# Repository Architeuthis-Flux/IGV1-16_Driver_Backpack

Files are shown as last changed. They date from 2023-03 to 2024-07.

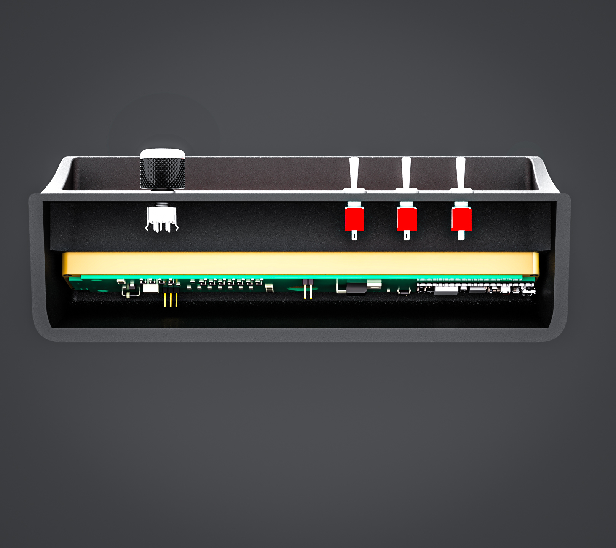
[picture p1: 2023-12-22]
Hardware/Enclosure_New Style/Renders/compass3_inclinometerStyled_2023-Jun-18_10-15-27PM-000_CustomizedView31835428946_png.jpg

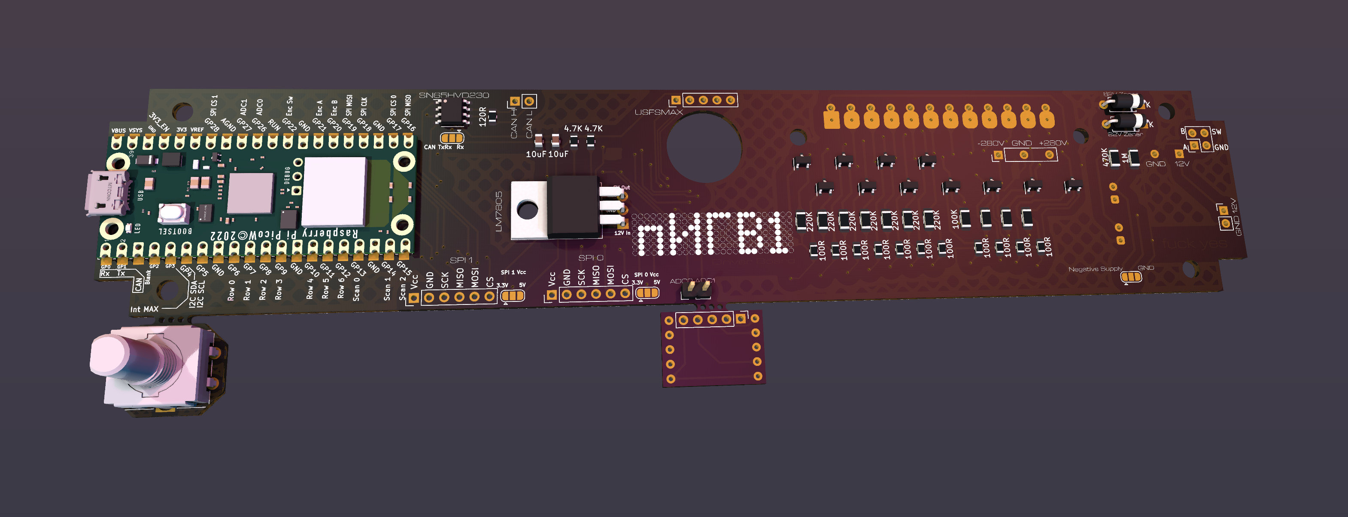
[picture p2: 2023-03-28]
Hardware/Screenshot 2023-03-19 at 2.08.38 PM.png

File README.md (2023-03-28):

# IGV1-16 Driver Backpack
This is a board that screws onto the back of an IGV1-16, GIPS-16 or Burroughs Self-Scan and handles the HV buffering between it and a RPi Pico W, among other things. 

[Here's the Hackaday.io page with more details about some of the hardware involved](https://hackaday.io/project/190028-igv1-16-car-compass)





I made a thing to handle the mess of wiring from the [IGV1-16 Compass](https://github.com/Architeuthis-Flux/IGV1-16-Compass) but I had a ton of extra board space and GPIO so I ended up making a somewhat generalized development board for these plasma scan displays. 

IGV1

Soon I'll be adding some code here that will be easier to use with whatever you end up doing with your plasma scan display. That other repo is just a small amount of display handling shoved into a huge mess of [USFSMAX sensor fusion module](https://github.com/gregtomasch/USFSMAX_MMC_Module/tree/master/MMC_USFS_MAX_Module_Dragonfly_Simple_Host_Utility_v0.0) code, and I'd like for people to be able to make this display show anything they like and not be confined to one specific use. 



For now, this is just the Kicad files for the hardware and some basic driving code for the Pico will be added in the next couple days. If you hve an idea for something cool to do with one of [these displays](https://www.ebay.com/itm/224643685691), let me know and I'll make sure you get a backpack board to play with. 

It uses one of these [cheap bipolar HV power supply modules](https://www.ebay.com/itm/295529826686) to generate the +280V and the (optional) -82V to drive the display. If you end up with one of these modules without the negative supply, there's a solder jumper on the board to instead drive the Blank line to ground. In which case it just needs to be held low a bit longer, giving you a bit less time to do other things between screen updates, but otherwise is totally fine.  





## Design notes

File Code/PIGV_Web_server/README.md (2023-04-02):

# pIGV-16 Web server scrolling text
This is code to have the Pico W host a simple web server that allows you to write text to be scrolled on the display

I'm using the [Arduino-Pico](https://github.com/earlephilhower/arduino-pico) core for this

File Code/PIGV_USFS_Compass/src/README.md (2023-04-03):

# pIGV1 Compass

This is the code for the car compass. 

It uses the [Arduino Pico](https://github.com/earlephilhower/arduino-pico) core and interfaces with a [USFSMAX Module](https://www.tindie.com/products/onehorse/usfsmax-module-and-carrier/) using [this excellent libraryification of the original interface code](https://github.com/PhiJu5/USFSMAX). But you don't need to download it, it's included in the files here because I needed to make a few modifications.

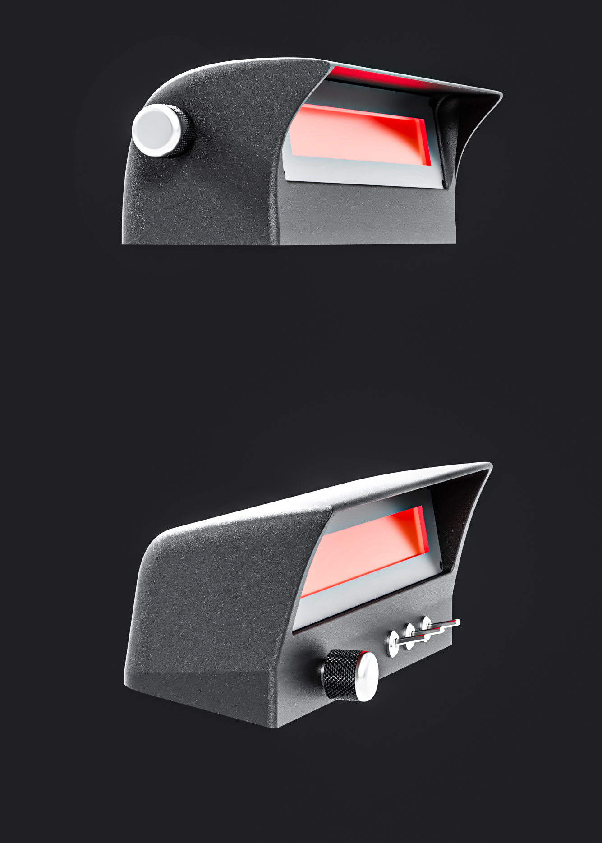
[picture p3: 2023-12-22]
Hardware/Enclosure_New Style/Renders/compass3_inclinometerStyled_2023-Jun-18_09-27-02PM-000_CustomizedView1432547207_png.jpg

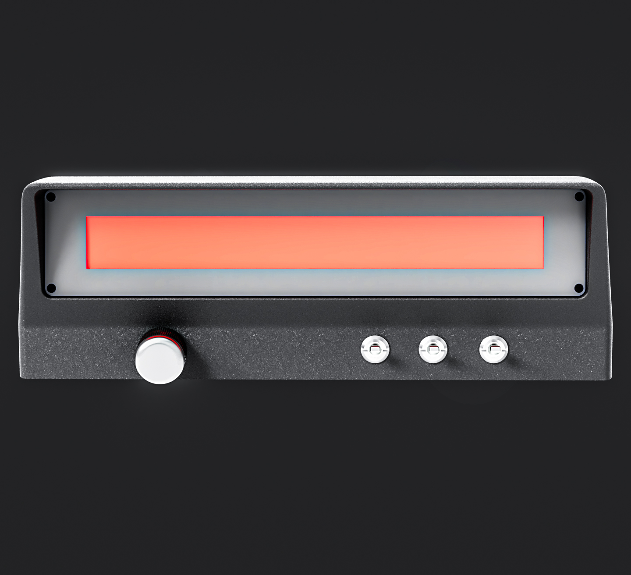
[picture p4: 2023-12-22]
Hardware/Enclosure_New Style/Renders/compass3_inclinometerStyled_2023-Jun-18_10-14-51PM-000_CustomizedView15648716872_png.jpg

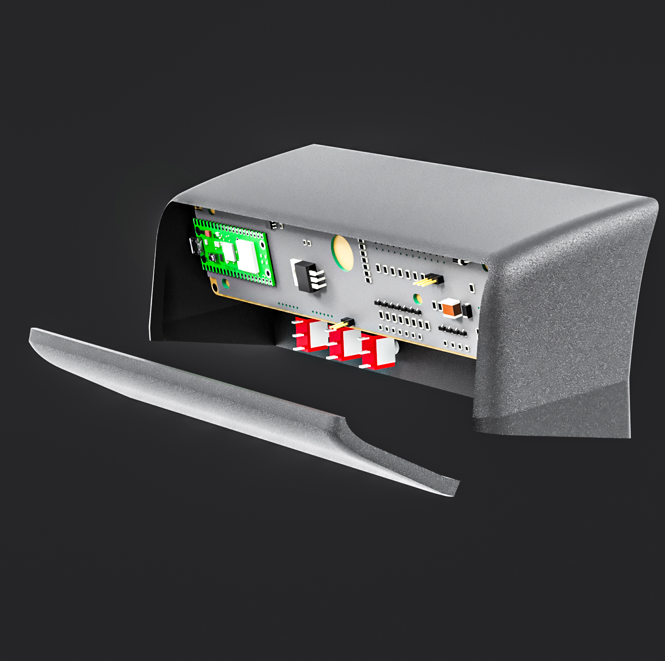
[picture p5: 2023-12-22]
Hardware/Enclosure_New Style/Renders/compass3_inclinometerStyled_2023-Jun-18_10-05-42PM-000_CustomizedView15776161031_png.jpg

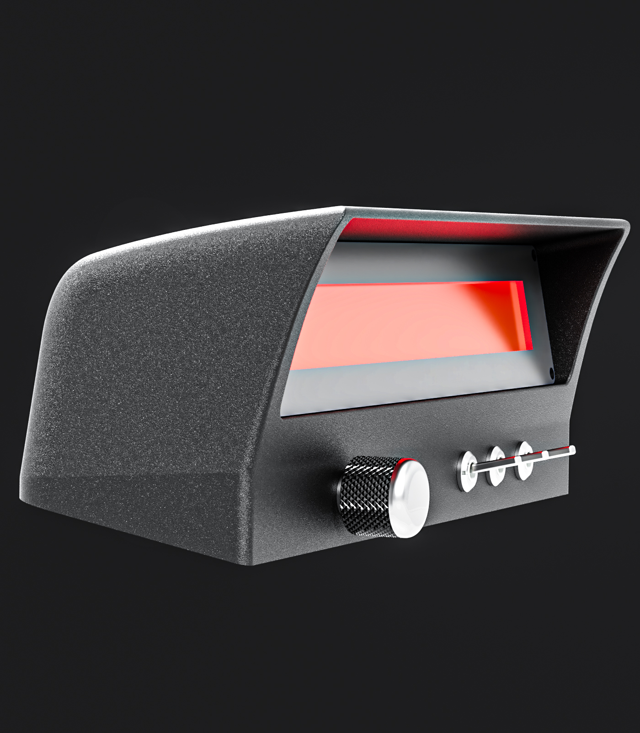
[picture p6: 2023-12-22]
Hardware/Enclosure_New Style/Renders/compass3_inclinometerStyled_2023-Jun-18_09-28-52PM-000_CustomizedView9031824127_png.jpg

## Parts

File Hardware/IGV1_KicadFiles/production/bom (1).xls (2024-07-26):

Comment | Designator | Footprint | JLCPCB Part #
10uF | C1,C2 | 805 | C15850
100K | R23 | 1206 | C507479
470K | R18 | 1206 | C966048
0R | R24,R25,R26 | 1206 | C346502
120R | R3 | 805 | C17437
1M | R27 | 1206 | C346738
LM7805 | U1 | TO-220-3_Horizontal_TabDown | C347289
220K | R11,R12,R13,R14,R15,R16,R17 | 1206 | C307948
MPSA42 | Q1,Q10,Q11,Q2,Q3,Q4,Q5,Q6,Q7,Q8,Q9 | SOT-23 | C426838
4.7K | R1,R2 | 805 | C105427
82VZener | D1,D2 | D_A-405_P7.62mm_Horizontal | C388153
SN65HVD230 | U3 | SOIC-8_3.9x4.9mm_P1.27mm | C12084
100R | R10,R19,R20,R21,R22,R4,R5,R6,R7,R8,R9 | 805 | C17408

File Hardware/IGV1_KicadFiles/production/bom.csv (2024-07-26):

Designator | Footprint | Quantity | Value | LCSC Part #
C1, C2 | 805 | 2 | 10uF | C15850
C3, C4, C5 | 805 | 3 | 100pF | C62768
C6, C7 | C_Radial_D6.3mm_H11.0mm_P2.50mm | 2 | 10uF
D1, D2 | D_A-405_P7.62mm_Horizontal | 2 | 82V Zener | C388153
J1 | USFSMAX | 1 | Conn_01x10_Pin
J10, J11 | PinHeader_2x02_P2.54mm_Vertical | 2 | Conn_01x04_Pin
J12 | PinHeader_1x05_P2.54mm_Vertical | 1 | Conn_01x05
J14 | PinHeader_1x05_P2.54mm_Vertical | 1 | USFSMAX
J2 | PinHeader_1x02_P2.54mm_Vertical | 1 | GND 12V
J3 | PinHeader_1x06_P2.54mm_Vertical_SPI | 1 | SPI 0
J4 | PinHeader_1x02_P2.54mm_Vertical | 1 | ADC0 ADC1
J5 | PinHeader_1x02_P2.54mm_Vertical | 1 | CAN_H CAN_L
J6 | PinHeader_1x06_P2.54mm_Vertical_SPI | 1 | SPI 1
J7 | PinHeader_1x03_P2.54mm_Vertical | 1 | GND 12V
J8 | PinHeader_1x06_P2.54mm_Vertical | 1 | -280V GND +280V
J9 | PinHeader_1x12_P2.54mm_Vertical | 1 | Conn_01x12_Pin
JP1 | SolderJumper-3_P1.3mm_Bridged12_RoundedPad1.0x1.5mm | 1 | CAN TxRx Rx
JP2 | SolderJumper-3_P1.3mm_Bridged12_RoundedPad1.0x1.5mm | 1 | SPI 0 Vcc
JP3 | SolderJumper-3_P1.3mm_Bridged12_RoundedPad1.0x1.5mm | 1 | SPI 1 Vcc
JP4 | SolderJumper-3_P1.3mm_Bridged12_RoundedPad1.0x1.5mm | 1 | Negative Supply GND
Q1, Q10, Q11, Q2, Q3, Q4, Q5, Q6, Q7, Q8, Q9 | SOT-23 | 11 | MPSA42 | C426838
R1, R2 | 805 | 2 | 4.7K | C313926
R10, R19, R20, R21, R22, R4, R5, R6, R7, R8, R9 | 805 | 11 | 100R | C17408
R11, R12, R13, R14, R15, R16, R17 | 1206 | 7 | 220K | C2759069
R18 | 1206 | 1 | 470K | C2759052
R23 | 1206 | 1 | 100K | C2759095
R24, R25, R26 | 1206 | 3 | 0R | C346502
R27 | 1206 | 1 | 1M | C2094730
R3 | 805 | 1 | 120R | C17437
SW1 | RotaryEncoder_Alps_EC12E-Switch_Vertical_H20mm | 1 | RotaryEncoder_Switch
U1 | TO-220-3_Horizontal_TabDown | 1 | LM7805 | C347289
U2 | RPi_Pico_SMD_TH_1 | 1 | Pico
U3 | SOIC-8_3.9x4.9mm_P1.27mm | 1 | SN65HVD230 | C5342107

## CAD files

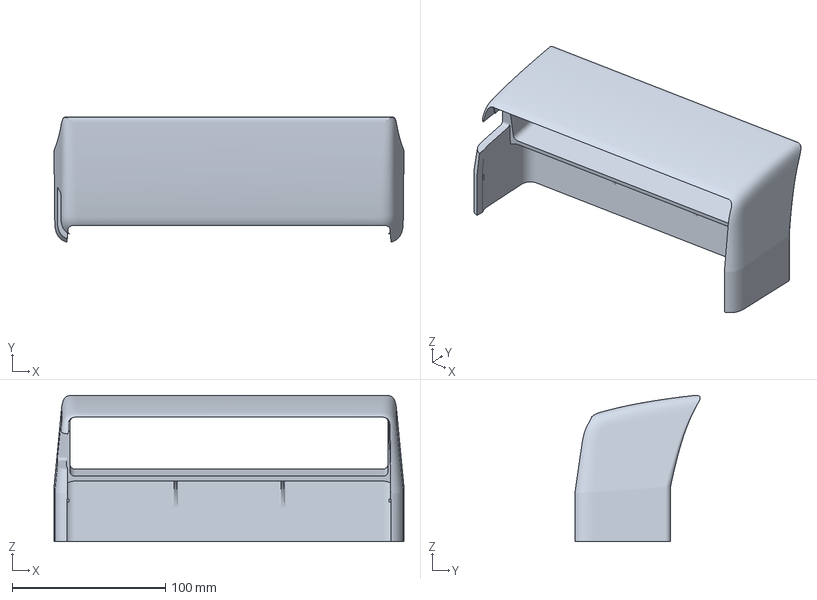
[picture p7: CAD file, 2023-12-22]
Hardware/Enclosure_New Style/compass3 inclinometerStyledJeepFront.3mf
228.4 x 81.8 x 95.5 mm

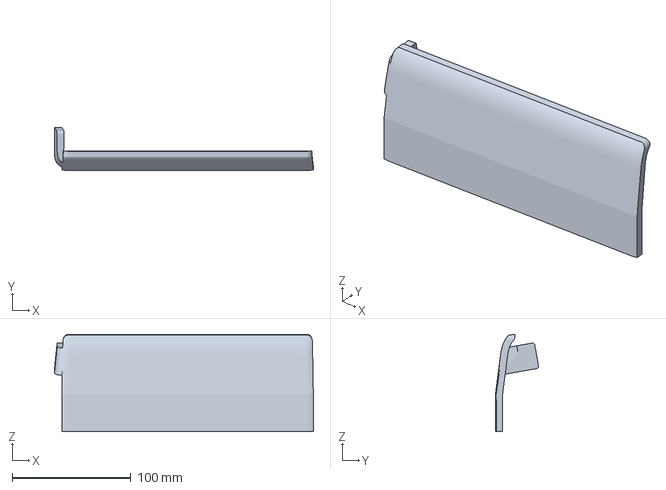
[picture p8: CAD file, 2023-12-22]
Hardware/Enclosure_New Style/compass3 inclinometerStyledJeepBack.3mf
217.9 x 36.2 x 81.9 mm

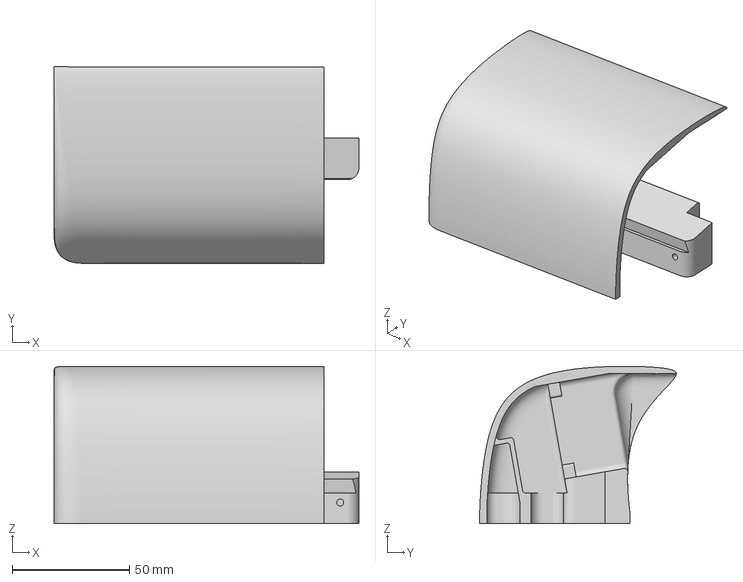
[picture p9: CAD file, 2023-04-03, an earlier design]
Hardware/CompassEnclosure_OLD/CompassRightSide.3mf
130.0 x 83.8 x 67.1 mm

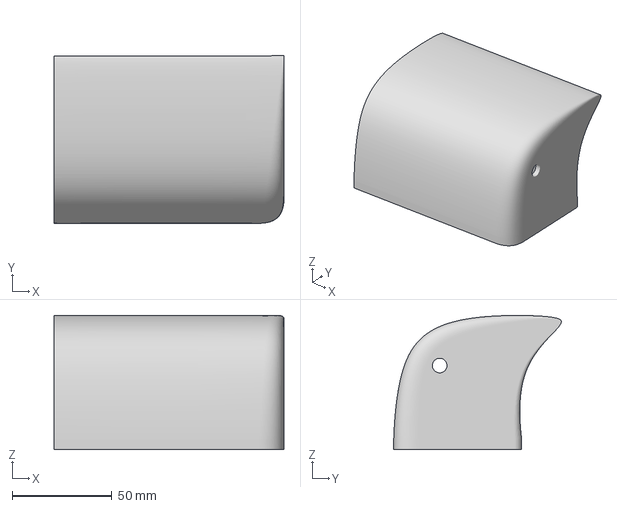
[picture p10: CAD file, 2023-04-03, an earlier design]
Hardware/CompassEnclosure_OLD/CompassLeftSide.3mf
115.0 x 83.8 x 67.1 mm

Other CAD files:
Hardware/CompassEnclosure_OLD/compass v6.f3d

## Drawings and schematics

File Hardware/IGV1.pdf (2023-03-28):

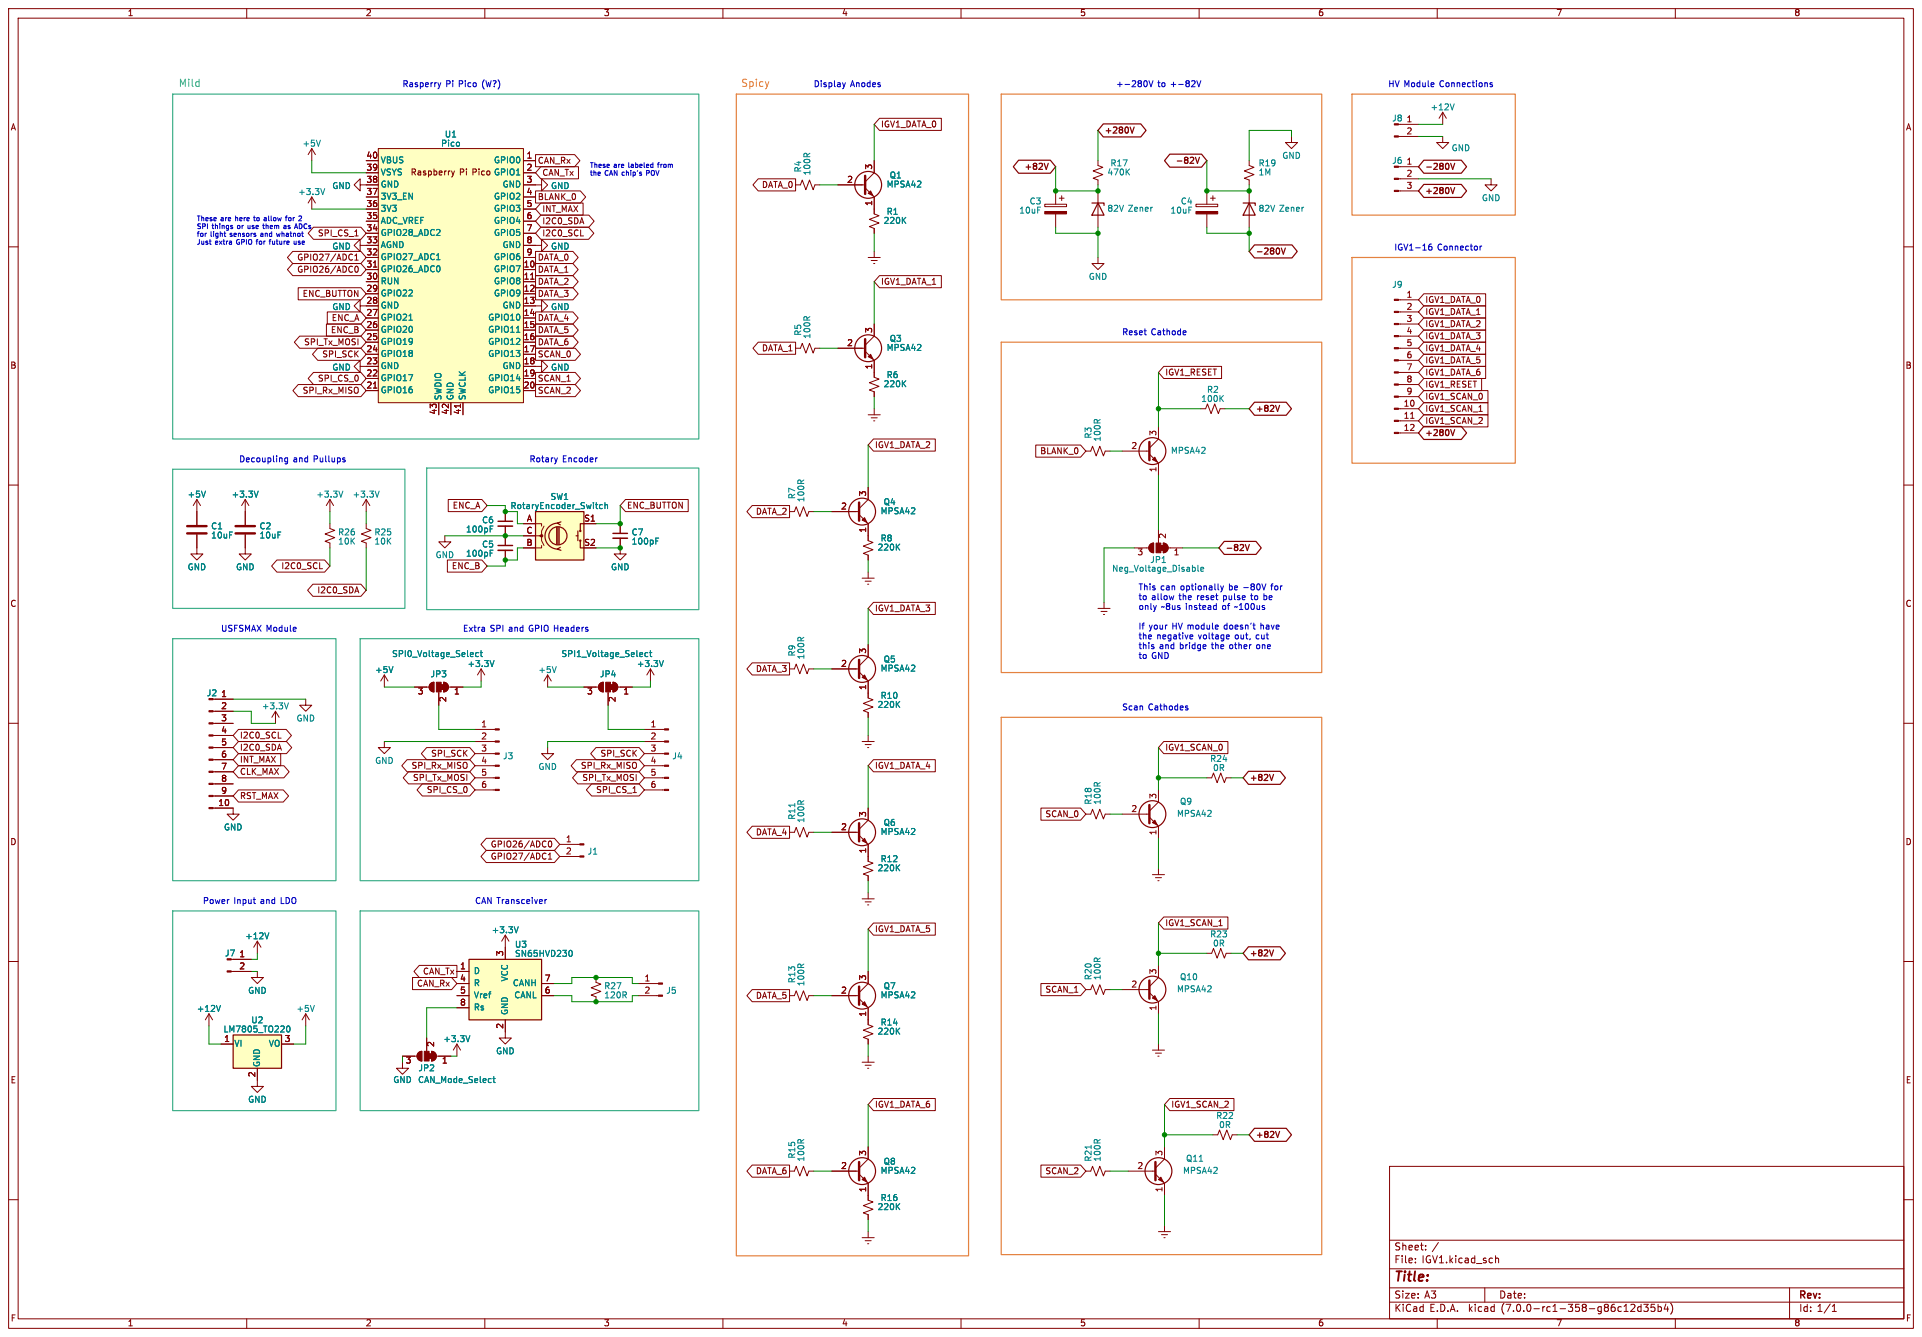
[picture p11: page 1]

These are labeled from
470K GND

These are here to allow for 2 SPI things or use them as ADCs

to allow the reset pulse to be
only ~8us instead of ~100us

Scan Cathodes Extra SPI and GPIO Headers CAN Transceiver

If your HV module doesn't have
the negative voltage out, cut
this and bridge the other one
to GND

Power Input and LDO

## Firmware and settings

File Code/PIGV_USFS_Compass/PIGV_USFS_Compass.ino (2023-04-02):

#include "bitmaps.h"

#include <string.h>

#include "i2c_api.h"
#include "quat2euler.h"
#include "report.h"
#include "USFSMAX.h"

#include "hardware/pio.h"
#include "quadrature.pio.h"

#include <EEPROM.h>

#include "MovingAverage.h"

#define QUADRATURE_A_PIN 21
#define QUADRATURE_B_PIN 20

MovingAverage<float, 32> filter;  //powers of 2 only   this sets how fast altitude responds


PIO pio = pio0;
uint offset, sm;

#define ENC_A 21      //ky-040 clk pin, add 100nF/0.1uF capacitors between pin & ground!!!
#define ENC_B 20      //ky-040 dt  pin, add 100nF/0.1uF capacitors between pin & ground!!!
#define BUTTONENC 22  //ky-040 sw  pin, add 100nF/0.1uF capacitors between pin & ground!!!

#define blank 2

#define scan3 15
#define scan2 14
#define scan1 13


#define row0 6
#define row1 7
#define row2 8
#define row3 9
#define row4 10
#define row5 11
#define row6 12


int scroll = 0;   //position of whatever is on the display, so this is the compass heading or text scroll
int scroll2 = 0;  // used to increment scroll for text scrolling (this value here is the start point)

int displayedMenu = 0;  //mode selection - 0 for compass  1 = Menu   2 = scrolling text

//general display stuff
char displayText[500] = { "Holy fuck guys! It's a pIGV1-16\0 " };  //this is where you put text to display (from wifi or serial or whatever) terminated with \0
int invertedChars[500];                                            // put 1 in locations where you want text to be knockout
unsigned char displayBuffer[3000];                                 //this is where the actual bitmap is loaded to be shown on the display


//compass specific stuff
int selectedStart = 0;  //this lets the display follow the selected menu items
unsigned char menuArray[6][20] = {
  { "Heading" }, { "Declination" }, { "Brightness" }, { "Altitude" }, { "Marker" }, { "Drive in circles!!" }
};
int menuArrayLengths[6] = { 7, 11, 10, 8, 6, 19 };
int hoveredMenuItem = 0;  // 1 = Heading   2 = Declination    3 = Brightness     4 = Calibrate
int selectedMenuItem = 0;
int menuItem = 0;  // 1 = Heading   2 = Declination    3 = Brightness     4 = Calibrate   5 = Marker
int marker = 180;
int markerFlag = 0;
int markerSetFlag = 0;  //1 for marker selection menu
int calibratingFlag = 0;
int calConfirm = 0;
int showHeading = 1;   //whether to show heading numbers on the left in the compass
int showAltitude = 0;  //this shows pressure altitude so it's not very accurate, but if you know the altitude of where you start it can be adjusted
int declinationSet = 0;
int Declination = 11;  // substitute your magnetic declination but really this wont matter because this is used to adjust the heading
float pressureOffset = 0.0;
int position = 0;

//scrolling text stuff
int charsInDisplay = 0;
const int numChars = 600;
char receivedChars[numChars];  // an array to store the received data
int scrollSpeed = 30;          //number of millisecods to wait before moving 1 pixel
unsigned long timeLast = 0;
int scrollCharPosition;

unsigned long previousMillis = 0;
const long interval = 100;


unsigned long previousMillisScroll;
int scanLocation = -1;  //keeps track of where we are in the cathode scanning sequence (-1 keeps it from scanning the first cycle)
int brightness = 120;   //number of microseconds to hold on each column of the display (works from like 130 - 270, above that it gets kinda flashy)
bool toggleButton = 1;
volatile bool pressed = 0;
int lastPosition = 0;
int oldPos = 0;

boolean newData = false;
volatile int encoder_value = 0;
int encoderOffset = 0;
int encoderRaw = 0;

int scrollFlag = 1;

static const uint8_t INT_PIN = 3;

// Geomagnetic field data for Lexington, Virginia on 8 June 2022.
// https://www.ngdc.noaa.gov/geomag/calculators/magcalc.shtml#igrfwmm
// Units are uT, angles are in decimal degrees.
static const float M_V = 42.0589f;
static const float M_H = 23.1087f;
static const float MAG_DECLINATION = 11.1477f;

static const uint32_t SERIAL_UPDATE_PERIOD_MSEC = 100;

// Dynamic Hard Iron corrector
static const bool ENABLE_DHI_CORRECTOR = false;

// Dynamic Hard Iron Corrector allgorithm (otherwise 3D)
static const bool USE_2D_DHI_CORRECTOR = false;

// I2C Clock Speed (Uncomment one only)
static const uint32_t I2C_CLOCK = 1000000; /* 100000 */ /* 400000 */

// Instantiate class object
USFSMAX usfsmax;

static bool gyroCalActive;

// Data-ready interrupt handler
static volatile bool dataReady = true;
static void handleInterrupt() {
  dataReady = true;
}

static void sendOneToProceed(void) {
  serialPrintMessage("Send '1' to continue...");

  while (true) {
    if (serialGetCharacter() == '1') {
      break;
    }
    delay(10);
  }
}

// Serial interface handler
static void serialInterfaceHandler() {
  uint8_t serial_input = 0;
  if (serialAvailable()) serial_input = serialGetCharacter();
  if (serial_input == '1') {  // Type '1' to initiate usfsmax Gyro Cal
    usfsmax.gyroCal();
    gyroCalActive = true;
  }

  // Type '2' to list current sensor calibration data
  if (serial_input == '2') {

    // Set I2C clock to 100kHz to read the calibration data from the MAX32660
    i2cSetClock(100000);
    delay(100);

    usfsmax.retrieveCalibration();

    // Resume high-speed I2C operation
    i2cSetClock(I2C_CLOCK);
    delay(100);

    serialReportCalibrationResults(&usfsmax);

    // Halt the serial monitor to let the user read the calibration data
    //sendOneToProceed();
  }

  // Type '3' to reset the DHI corrector
  if (serial_input == '3') { usfsmax.resetDhi(); }
  serial_input = 0;
}


void setup() {


  pinMode(ENC_A, INPUT_PULLUP);
  pinMode(ENC_B, INPUT_PULLUP);

  pinMode(BUTTONENC, INPUT_PULLUP);
  displayedMenu = 3;
  //loadDisplayBuffer();
  //writeNeon();
  EEPROM.begin(64);
  offset = pio_add_program(pio, &quadrature_program);
  sm = pio_claim_unused_sm(pio, true);
  quadrature_program_init(pio, sm, offset, QUADRATURE_A_PIN, QUADRATURE_B_PIN);

  usfsmax.setGeoMag(M_V, M_H, MAG_DECLINATION);

  // Open serial port
  Serial.begin(115200);
  delay(20);

  // Initialize usfsmax I2C bus
  i2cBegin();
  delay(10);
  i2cSetClock(100000);
  delay(20);

  Serial.println("Initializing usfsmax...\n");
  usfsmax.begin();

  // Set the I2C clock to high speed for run-mode data collection
  i2cSetClock(I2C_CLOCK);
  delay(1000);

  // Attach interrupt
  pinMode(INT_PIN, INPUT);
  attachInterrupt(INT_PIN, handleInterrupt, RISING);

  serialPrintMessage("USFXMAX_0 successfully initialized!\n");
  Serial.begin(115200);

  EEPROM.get(0, Declination);


  EEPROM.get(10, brightness);
  if (brightness > 500 || brightness < 50) {
    brightness = 160;
    EEPROM.put(10, brightness);
  }

  EEPROM.get(20, marker);
  if (marker > 360 || marker < 0) {
    marker = 180;
    EEPROM.put(20, marker);
  }

  EEPROM.get(30, showHeading);
  if (showHeading != 1 || showHeading != 0) {
    showHeading = 1;
    EEPROM.put(30, showHeading);
  }
}

int showSplash = 1;

unsigned long holdButton = 0;
unsigned long holdButtonFirstPressed = 0;
unsigned long lastPress = 0;
int pressFlag = 0;

int newPositionEncoder = 0;

void loop() {


  pio_sm_exec_wait_blocking(pio, sm, pio_encode_in(pio_x, 32));

  encoderRaw = (pio_sm_get_blocking(pio, sm));

  encoder_value = encoderRaw - encoderOffset;


  if (encoder_value != newPositionEncoder) {
    position = newPositionEncoder;
    encoderISR();
  }



  int buttonState = digitalRead(BUTTONENC);


  // interrupts();
  if (pressed == 1) encoderButtonISR();



  static float angles[3];
  static uint32_t count;
  static uint32_t last_refresh;

  if (dataReady) {

    count++;

    dataReady = false;

    usfsmax.update();

    if (usfsmax.gotQuat()) {
      float quat[4] = {};
      usfsmax.readQuat(quat);
      quat2euler(quat, angles);
    }
  }

  if (showSplash == 1) {

    if (millis() < 2000 || (usfsmax.gotQuat() == 0)) {
      scroll2 = 0;
      displayedMenu = 3;
    } else {
      showSplash = 0;
      displayedMenu = 0;
      scroll2 = (int)angles[2];
    }
  } else {
    scroll2 = (int)angles[2];
  }


  if (millis() - last_refresh > SERIAL_UPDATE_PERIOD_MSEC) {


    //Serial.println(gyroCalActive);

    last_refresh = millis();

    serialInterfaceHandler();

    serialReportAngles(count, angles);
  }


  if (buttonState == 0) {

    holdButton = millis();
    if (holdButton - holdButtonFirstPressed > 7000) {
      calibratingFlag = 1;
      usfsmax.resetDhi();

    } else {
    }


  } else {
    holdButtonFirstPressed = millis();
  }

  if (buttonState == 0 && (millis() - lastPress > 200) && pressFlag == 0) {
    pressed = 1;
    lastPress = millis();
    pressFlag = 1;

  } else if (buttonState == 1) {
    pressFlag = 0;
    pressed = 0;
  }
}

void pressedEncoder() {
  //holdButtonFirstPressed = millis();
  pressed = 1;
}

void encoderISR() {
  //encoder.readAB();


  newPositionEncoder = encoder_value;  //encoder.getPosition();
  if (declinationSet == 1) {

    Declination = (position % 360);
    EEPROM.put(0, Declination);
  }

  if (selectedMenuItem == 3) {

    int brightnessIncrement = 5;

    switch (brightness) {
      case 0 ... 99:
        brightnessIncrement = 1;
        break;

      case 100 ... 179:
        brightnessIncrement = 1;
        break;

      case 180 ... 270:
        brightnessIncrement = 1;
        break;

      case 271 ... 350:
        brightnessIncrement = 2;
        break;

      case 351 ... 500:
        brightnessIncrement = 15;
        break;

      case 501 ... 2000:
        brightness /= 10;
        brightness *= 10;
        brightnessIncrement = 50;
        break;

      case 2001 ... 2000000:
        brightness /= 10;
        brightness *= 10;
        brightnessIncrement = 200;
        break;
    }


    if (oldPos < position) {
      brightness += brightnessIncrement;
      EEPROM.put(10, brightness);

    } else {
      brightness -= brightnessIncrement;
      EEPROM.put(10, brightness);
    }
    oldPos = position;
  }

  if (selectedMenuItem == 5) {

    if (oldPos < position) {
      marker += 1;
      if (marker >= 360) marker = 0;
    } else {
      marker -= 1;
      if (marker < 0) marker = 359;
    }
    oldPos = position;

    marker = marker % 360;
    EEPROM.put(20, marker);
  }


  if (showAltitude == 1) {

    if (oldPos < position) {
      pressureOffset += 0.05;

    } else {
      pressureOffset -= 0.05;
    }
    oldPos = position;
    EEPROM.put(40, pressureOffset);
  }


  // letter = abs(position);
  hoveredMenuItem = abs(position % 7);
  //position = Declination;
}


void encoderButtonISR() {

  pressed = 0;


  if (selectedMenuItem > 5) selectedMenuItem = 0;
  //while(1);
  //noInterrupts();
  toggleButton = !toggleButton;




  if (selectedMenuItem == 5) {
    declinationSet = 0;
    showAltitude = 0;
    showHeading = 1;
    EEPROM.put(20, marker);
    markerSetFlag = 0;

    hoveredMenuItem = 0;
    selectedMenuItem = hoveredMenuItem;
    displayedMenu = !displayedMenu;
    //interrupts();
    return;
  }
  selectedMenuItem = hoveredMenuItem;

  if (selectedMenuItem == 1) {
    //showHeading = !showHeading;

    declinationSet = 0;
    encoderOffset = position;
    //encoder.setPosition (0);

    if (showHeading == 1) {
      showAltitude = 0;
      showHeading = 0;
    } else {
      showAltitude = 0;
      showHeading = 1;
    }
    //selectedMenuItem = 0;
    EEPROM.put(30, showHeading);
    hoveredMenuItem = 0;
    selectedMenuItem = 0;
    //displayedMenu = 0;
    displayedMenu = !displayedMenu;

    return;
  }

  if (selectedMenuItem == 2) {
    if (declinationSet == 0) {
      // encoder.setPosition(Declination);
      declinationSet = 1;
      showHeading = 1;
      hoveredMenuItem = 2;
      selectedMenuItem = 2;
      displayedMenu = 0;
      EEPROM.put(0, Declination);
    } else {
      declinationSet = 0;
      EEPROM.put(0, Declination);
      EEPROM.get(30, showHeading);
      hoveredMenuItem = 0;
      selectedMenuItem = 0;
      //selectedMenuItem = hoveredMenuItem;
      displayedMenu = 0;
      //interrupts();
    }
    return;
  } else {
    declinationSet = 0;
  }

  if (selectedMenuItem == 3) {
    EEPROM.put(10, brightness);
    declinationSet = 0;
    //hoveredMenuItem = 0;

    //displayedMenu = !displayedMenu;
  }


  if (selectedMenuItem == 5) {

    declinationSet = 0;
    if (markerFlag == 0) {
      markerFlag = 1;
      markerSetFlag = 1;


    } else if (markerFlag == 1) {
      markerFlag = 0;
      markerSetFlag = 0;
      hoveredMenuItem = 0;
      selectedMenuItem = hoveredMenuItem;
    }
  }


  if (selectedMenuItem == 4) {
    declinationSet = 0;
    encoderOffset = position;
    if (showAltitude == 0) {
      showAltitude = 1;
      showHeading = 0;
    } else {
      showAltitude = 0;

      //EEPROM.get(30, showHeading);
      //showHeading = 1;
    }
    hoveredMenuItem = 0;
    selectedMenuItem = 0;
  }


  displayedMenu = !displayedMenu;


  //hoveredMenuItem = 0;
  //interrupts();
}






void setup1() {
  pinMode(scan1, OUTPUT_8MA);
  pinMode(scan2, OUTPUT_8MA);
  pinMode(scan3, OUTPUT_8MA);

  pinMode(row0, OUTPUT_8MA);
  pinMode(row1, OUTPUT_8MA);
  pinMode(row2, OUTPUT_8MA);
  pinMode(row3, OUTPUT_8MA);
  pinMode(row4, OUTPUT_8MA);
  pinMode(row5, OUTPUT_8MA);
  pinMode(row6, OUTPUT_8MA);

  pinMode(blank, OUTPUT_8MA);
}

void loop1() {

 

  loadDisplayBuffer();
  writeNeon();
}




void showHeadingNumbers(int headingToShow) {

  // if (displayedMenu == 1) return;

  int numberCount = 0;
  int rowCount = 0;
  int scrollValue = scroll;

  int lastDigit = 1;
  int menuReminderAscii = 78;
  int asciiInt[12] = { -16, -16, -16, -16, -16, -16, -16, -16, -16, -16, -16, -16 };

  if ((showHeading == 1 || declinationSet == 1 || markerSetFlag == 1 && showAltitude != 1) && selectedMenuItem != 3) {
    headingToShow = (headingToShow + 280) % 360;
  }

  if (headingToShow < 10) {

    asciiInt[1] = headingToShow;


  } else if (headingToShow >= 10 && headingToShow < 100) {

    asciiInt[2] = headingToShow % 10;
    asciiInt[1] = headingToShow / 10;

  } else if (headingToShow >= 100 && headingToShow < 1000) {

    asciiInt[3] = headingToShow % 10;
    asciiInt[2] = (headingToShow / 10) % 10;
    asciiInt[1] = (headingToShow / 100) % 10;

  } else if (headingToShow >= 1000 && headingToShow < 10000) {

    asciiInt[4] = headingToShow % 10;
    asciiInt[3] = (headingToShow / 10) % 10;
    asciiInt[2] = (headingToShow / 100) % 10;
    asciiInt[1] = (headingToShow / 1000) % 10;

  } else if (headingToShow >= 10000) {  //I know heading will never be more than 3 digits, but if you want to show different numbers you can up to 99999

    asciiInt[5] = headingToShow % 10;
    asciiInt[4] = (headingToShow / 10) % 10;
    asciiInt[3] = (headingToShow / 100) % 10;
    asciiInt[2] = (headingToShow / 1000) % 10;
    asciiInt[1] = (headingToShow / 10000) % 10;
  }


  for (int i = 1; i < 9; i++) {  //finds the last digit to replace with menuReminder bitmap
    if (asciiInt[i] == -16) {
      lastDigit = i;
      break;
    }
  }
  switch (selectedMenuItem) {  //these change the units to thing to remind you what you're doing
    case 0:
      menuReminderAscii = 78;
      break;

    case 1:
      break;

    case 2:
      menuReminderAscii = 79;
      break;

    case 3:
      menuReminderAscii = 81;
      break;

    case 5:
      menuReminderAscii = 80;
      break;
  }

  if (calibratingFlag == 1) {
    menuReminderAscii = 82;
  }

  if (showAltitude == 1 && showHeading == 0 && selectedMenuItem != 2 && selectedMenuItem != 3) {
    menuReminderAscii = 83;
  }

  if (declinationSet == 1) {
    menuReminderAscii = 79;
  }

  asciiInt[lastDigit] = menuReminderAscii;

  if (asciiInt[1] == 1) rowCount -= 1;

  for (int j = 1; j <= 11; j++) {  //this actually adds the heading stuff to the display buffer

    for (int k = 0; k < 5; k++) {

      if (k >= 5) {
        displayBuffer[(scrollValue + rowCount) % 360] = 0b11111111;  //this adds a blank column between letters
      } else {
        displayBuffer[(scrollValue + rowCount) % 360] = ~charBitmaps[asciiInt[j] + 16][k];
      }
      rowCount++;
    }


    displayBuffer[(scrollValue + rowCount) % 360] = 0b11111111;
    rowCount++;

    if (j + 1 == lastDigit && menuReminderAscii != 78) {
      displayBuffer[(scrollValue + rowCount) % 360] = 0b11111111;
      rowCount++;
    }

    if (asciiInt[j] == 1) rowCount -= 1;  //this is because the digit 1 is narrower than the rest and the spacing was bugging me //#keming

    if (asciiInt[j + 1] == -16) {                                //this adds space between the heading and the compass
      if (menuReminderAscii != 78 && menuReminderAscii != 82) {  //different spacings looked right depending on the menuReminder
        displayBuffer[(scrollValue + rowCount) % 360] = 0b11111111;
        displayBuffer[(scrollValue + rowCount + 1) % 360] = 0b11111111;
        displayBuffer[(scrollValue + rowCount + 2) % 360] = 0b11111111;
      }
      return;
    }
  }
}

void loadDisplayBuffer(void) {  //this fills displayBuffer[] with data depending on the menu
  static int halftoneStep = 0;

  switch (displayedMenu) {
    case 3:
      {
        //hoveredMenuItem = 0;
        //showHeading = 0;
        for (int i = 0; i < 112; i++) {

          displayBuffer[i] = splash[halftoneStep][i];
        }
        halftoneStep++;
        if (halftoneStep >= 3) halftoneStep = 1;
        break;
      }
    case 0:  //compass
      {

        hoveredMenuItem = 0;
        //scroll = scroll2;
        int decLoc = (scroll + 55) % 360;

        for (int i = 0; i < 360; i++) {

          displayBuffer[i] = compass[i];
          if (marker == i && markerFlag == 1) {

            displayBuffer[i] = 0b0000000;
          }
          if (declinationSet == 1 && i == decLoc) {
            displayBuffer[i] = 0b0000000;
          }
        }
      }
      break;

    case 1:  //compass menu
      {
        int letterCount = 0;
        int menuCount = 0;

        int displayTextLocation = 0;


        for (int k = 0; k < 5; k++) {

          for (int i = 0; i < menuArrayLengths[k]; i++) {
            displayText[displayTextLocation] = menuArray[k][i];
            if (hoveredMenuItem == k + 1) {
              invertedChars[displayTextLocation] = 1;

            } else {

              invertedChars[displayTextLocation] = 0;
            }

            displayTextLocation++;
          }
          displayText[displayTextLocation] = ' ';
          displayTextLocation++;
        }



        for (int i = 0; i < 40; i++) {
          displayBuffer[i] = 0b01111111;
        }

        for (int i = 0; i < 360; i += 6) {

          for (int j = 0; j < 6; j++) {

            int letterInt = displayText[i / 6] - 32;

            if (letterInt > 92 || letterInt < 0) letterInt = 0;


            if (invertedChars[i / 6] == 1) {
              if (j == 0) {
                displayBuffer[i + j - 1 + 40] = 0b00000000;
              }
              if (j < 5) {

                displayBuffer[i + j + 40] = charBitmaps[letterInt][j];

              } else {
                displayBuffer[i + j + 40] = 0b00000000;
              }
            } else {
              if (j < 5) {

                displayBuffer[i + j + 40] = ~charBitmaps[letterInt][j];

              } else {
                displayBuffer[i + j + 40] = 0b11111111;
              }
            }
          }
          letterCount++;
        }

        break;
      }
    case 2:  //scrolling text
      {


        int displayTextLocation2 = 0;
        int endFlag = 0;
        int bufferPosition = 0;
        int foundEndingFlag = 0;

        for (int i = 0; i < sizeof(displayBuffer); i += 6) {


          if (displayText[(i / 6)] == '\0' && foundEndingFlag == 0) {
            foundEndingFlag = 1;
            charsInDisplay = (i / 6) + 1;
            //bufferPosition = 0;
          }

          if ((bufferPosition / 6) > charsInDisplay)  //this makes it fill the entire buffer with repeated copies of displayText[]
          {                                           //if speed is an issue you can change this loop to not waste so many cycles
            endFlag = 1;
            bufferPosition = -6;
          } else {
            endFlag = 0;
          }

          for (int j = 0; j < 6; j++) {

            if (endFlag == 0) {
              int letterInt = displayText[bufferPosition / 6] - 32;

              if (letterInt > 92 || letterInt < 0) letterInt = 0;


              if (invertedChars[i / 6] == 1) {  //for inverted charachters
                if (j == 0) {
                  displayBuffer[i + j - 1] = 0b00000000;
                }
                if (j < 5) {

                  displayBuffer[i + j] = charBitmaps[letterInt][j];

                } else {
                  displayBuffer[bufferPosition + j] = 0b00000000;
                }
              } else {  //non inverted charachters
                if (j < 5) {

                  displayBuffer[i + j] = ~charBitmaps[letterInt][j];

                } else {
                  displayBuffer[i + j] = 0b11111111;
                }
              }
            } else {

              displayBuffer[i + j] = 0b11111111;
              //endFlag++;
            }
          }

          bufferPosition += 6;
        }
        break;
      }
  }
}
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

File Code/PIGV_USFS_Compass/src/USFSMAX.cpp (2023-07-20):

/*
 * Copyright (c) 2022 Gregory Tomasch and Simon D. Levy.  All rights reserved.
 *
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
 * THE SOFTWARE IS PROVIDED "AS IS", WITHOUT WARRANTY OF ANY KIND, EXPRESS OR
 * IMPLIED, INCLUDING BUT NOT LIMITED TO THE WARRANTIES OF MERCHANTABILITY,
 * FITNESS FOR A PARTICULAR PURPOSE AND NONINFRINGEMENT.  IN NO EVENT SHALL THE
 * CONTRIBUTORS OR COPYRIGHT HOLDERS BE LIABLE FOR ANY CLAIM, DAMAGES OR OTHER
 * LIABILITY, WHETHER IN AN ACTION OF CONTRACT, TORT OR OTHERWISE, ARISING
 * FROM, OUT OF OR IN CONNECTION WITH THE SOFTWARE OR THE USE OR OTHER DEALINGS
 * WITH THE SOFTWARE.
 */

#if defined(ARDUINO)
#include <Arduino.h>
#else
#include <stdbool.h>
#include <stdint.h>
#include <string.h>
#include <wiringPi.h>
#endif

#include "USFSMAX.h"
#include "i2c_api.h"

// AHRS filters follow ENU convention
void USFSMAX::accOrientation(float sensorValues[3], float accData[3])
{
    accData[USFSMAX::EAST]  = +sensorValues[0];
    accData[USFSMAX::NORTH] = +sensorValues[1];  
    accData[USFSMAX::UP]    = +sensorValues[2];
}

void USFSMAX::baroGetAdc()
{
    uint8_t bytes[3];

    i2cReadBytes(MAX32660_ADDR, BARO_XL, 3, bytes);
    baroADC = (int32_t)bytes[2] << 16 | (int32_t)bytes[1] << 8 | bytes[0];
}

void USFSMAX::begin(const bool enableDhiCorrector, const bool use2DDhiCorrector)
{
    uint8_t STAT;
    uint8_t ConfigByte;

    // Read the coprocessor's current fusion status
    STAT = i2cReadByte(MAX32660_ADDR, FUSION_STATUS);                                                                         
    delay(100);
Serial.println(STAT,HEX);
    if (STAT == 0) {

        // Stop sensor fusion
        i2cWriteByte(MAX32660_ADDR, FUSION_START_STOP, 0x00);  

        delay(100);

        // Upload configuration structure variable
        USFSMAX::uploadConfig();

        // Re-start sensor fusion
        ConfigByte = ((0x01 | EulerQuatFlag << 1) | ScaledSensorDataFlag << 2);              
        // Set bit0 to re-start fusion; adjust bit1, bit2 for desired output options
        i2cWriteByte(MAX32660_ADDR, FUSION_START_STOP, ConfigByte);

        delay(100);

        // Poll the FUSION_STATUS register to see if fusion has resumed
        while(1)
        {
          
            delay(10);
            STAT = i2cReadByte(MAX32660_ADDR, FUSION_STATUS);
            if ((STAT & FUSION_RUNNING_MASK)) {break;}
        }
    }

    // Check for sensor errors
    STAT = i2cReadByte(MAX32660_ADDR, SENS_ERR_STAT);
    if (STAT !=0) {
        while(1) {
          Serial.println("fuck");
          return;
          }
    }

    while(1){
STAT = i2cReadByte(MAX32660_ADDR, CALIBRATION_STATUS);
Serial.println(STAT,BIN);
STAT = STAT & 0b00000001;
if (STAT == 0)
{
  delay(100);
  break;
}
delay(100);
    }

/*
delay(200);
    if (enableDhiCorrector) {
        if (use2DDhiCorrector) {
            // Enable DHI corrector, 2D (0x10|0x50)
            i2cWriteByte(MAX32660_ADDR, CALIBRATION_REQUEST, 0xD0);
        } else {
            // Enable DHI corrector, 3D (0x10)
            i2cWriteByte(MAX32660_ADDR, CALIBRATION_REQUEST, 0x10);
        } }

    */
    delay(200);

    //retrieveCalibration();

    //delay(500);
}

void USFSMAX::retrieveCalibration(void)
{
  delay(100);
  Serial.println("gyro");
    delay(100);
  
    USFSMAX::retrieveFullGyroCal();
    delay(100);
     Serial.println("accel");
    delay(100);

    USFSMAX::retrieveFullAccelCal();
    delay(100);
     Serial.println("ellip");
    delay(100);

    USFSMAX::retrieveEllipMagCal();
    delay(100);
     Serial.println("mag");
    delay(100);

    USFSMAX::retrieveFinalMagCal();
    delay(100);
}

void USFSMAX::accGetAdc()
{
    uint8_t bytes[6];

    i2cReadBytes(MAX32660_ADDR, A_X_L, 6, bytes);
    accADC[0] = ((int16_t)bytes[1] << 8) | bytes[0];
    accADC[1] = ((int16_t)bytes[3] << 8) | bytes[2];
    accADC[2] = ((int16_t)bytes[5] << 8) | bytes[4];
}

float USFSMAX::gyroDpsPerCount(void)
{
    float f = 0;

    switch (config.Gscale) {
        case GYRO_SCALE_125_DPS:
            f = 125;
            break;
        case GYRO_SCALE_250_DPS:
            f = 250;
            break;
        case GYRO_SCALE_500_DPS:
            f = 500;
            break;
        case GYRO_SCALE_1000_DPS:
            f = 1000;
            break;
        case GYRO_SCALE_2000_DPS:
            f = 2000;
            break;
    }

    return f * 3.5e-5;
}

void USFSMAX::getDhiRsq()
{
    i2cReadByte(MAX32660_ADDR, CALIBRATION_STATUS);   

    uint8_t bytes[2];

    i2cReadBytes(MAX32660_ADDR, DHI_RSQ_L, 2, bytes);
    Rsq = ((float)((int16_t)bytes[1] << 8 | bytes[0]))/10000.0f;

    Serial.println (Rsq);
}

void USFSMAX::getMxMy()
{
    uint8_t bytes[4];
    int16_t H[2];

    i2cReadBytes(MAX32660_ADDR, MX_L, 4, bytes);

    H[0] = ((int16_t)bytes[1] << 8) | bytes[0];
    H[1] = ((int16_t)bytes[3] << 8) | bytes[2];

    Mx = ((float)H[0])*UT_per_Count;
    My = ((float)H[1])*UT_per_Count;
}
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

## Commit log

2023-07-20 Fixed calibration lockup
2023-12-22 Added new enclosure
    [CompassLeftSide.3mf, CompassRightSide.3mf, compass v6.f3d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]
2024-07-26 New version
    [IGV1.kicad_sch, bom (1).xls, bom.csv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]
